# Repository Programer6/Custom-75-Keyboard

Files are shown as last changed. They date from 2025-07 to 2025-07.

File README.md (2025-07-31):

# Wireless 75% Keyboard

This is the documentation for  designed completely from scratch.

For the firmware, I chose ZMK. Since this is a wireless build using the `nice!nano`, ZMK's powerful features and Bluetooth support were a perfect fit, even if it meant a steeper learning curve than like KMK which I have used before.

# Hardware Features
- 74-key, 70% layout with a function row.
- Wireless Bluetooth connectivity via a `nice!nano` microcontroller.
- `MCP23017` I/O expander to simplify wiring and save controller pins.
- 1x Rotary Encoder for volume or scrolling.
- Onboard potentiometer for screen brightness adjustment.
- Powered by a LiPo battery.

## Images

| Schematic  |
| :---: |
| Screenshot 2025-07-31 at 1 52 47 PM|
| Screenshot 2025-07-31 at 1 53 02 PM |

| PCB Layout |
| :---: |
| Screenshot 2025-07-31 at 1 53 25 PM |

| 3D Case Design |
| :---: |
| Screenshot 2025-07-31 at 1 54 39 PM |

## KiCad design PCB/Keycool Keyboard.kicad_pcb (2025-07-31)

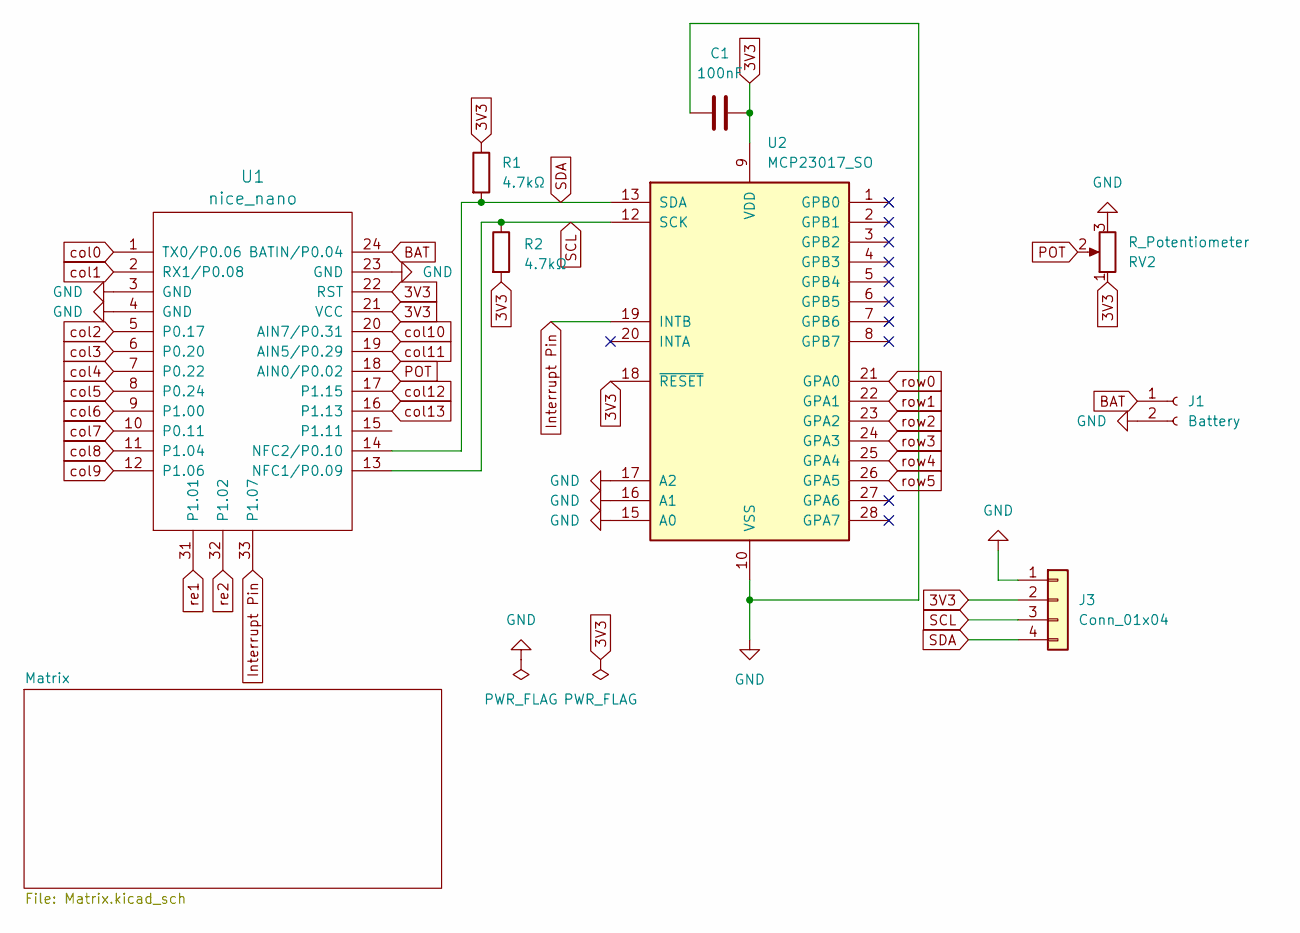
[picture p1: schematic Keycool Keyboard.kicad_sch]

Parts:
C1: 100nF; C_0805_2012Metric_Pad1.18x1.45mm_HandSolder
J1: Battery; JST_XH_B2B-XH-AM_1x02_P2.50mm_Vertical
J3: Conn_01x04; SSD1306-0.91-OLED-4pin-128x32
R1, R2: 4.7kΩ; R_0805_2012Metric_Pad1.20x1.40mm_HandSolder
RV2: R_Potentiometer; Sliding_Pot
U1: nice_nano
U2: MCP23017_SO; SOIC-28W_7.5x17.9mm_P1.27mm

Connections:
3V3: C1.2, J3.2, R1.1, R2.2, RV2.1, U1.21 (VCC), U1.22 (RST), U2.9 (VDD), U2.18 (~RESET)
BAT: J1.1, U1.24 (BATIN/P0.04)
GND: C1.1, J1.2, J3.1, RV2.3, U1.3 (GND), U1.4 (GND), U1.23 (GND), U2.10 (VSS), U2.15 (A0), U2.16 (A1), U2.17 (A2); also elsewhere on the board
Interrupt Pin: U1.33 (P1.07), U2.19 (INTB)
POT: RV2.2, U1.18 (AIN0/P0.02)
SCL: J3.3, R2.1, U1.13 (NFC1/P0.09), U2.12 (SCK)
SDA: J3.4, R1.2, U1.14 (NFC2/P0.10), U2.13 (SDA)
col0: U1.1 (TX0/P0.06); also elsewhere on the board
col1: U1.2 (RX1/P0.08); also elsewhere on the board
col2: U1.5 (P0.17); also elsewhere on the board
col3: U1.6 (P0.20); also elsewhere on the board
col4: U1.7 (P0.22); also elsewhere on the board
col5: U1.8 (P0.24); also elsewhere on the board
col6: U1.9 (P1.00); also elsewhere on the board
col7: U1.10 (P0.11); also elsewhere on the board
col8: U1.11 (P1.04); also elsewhere on the board
col9: U1.12 (P1.06); also elsewhere on the board
col10: U1.20 (AIN7/P0.31); also elsewhere on the board
col11: U1.19 (AIN5/P0.29); also elsewhere on the board
col12: U1.17 (P1.15); also elsewhere on the board
col13: U1.16 (P1.13); also elsewhere on the board
re1: U1.31 (P1.01); also elsewhere on the board
re2: U1.32 (P1.02); also elsewhere on the board
row0: U2.21 (GPA0); also elsewhere on the board
row1: U2.22 (GPA1); also elsewhere on the board
row2: U2.23 (GPA2); also elsewhere on the board
row3: U2.24 (GPA3); also elsewhere on the board
row4: U2.25 (GPA4); also elsewhere on the board
row5: U2.26 (GPA5); also elsewhere on the board

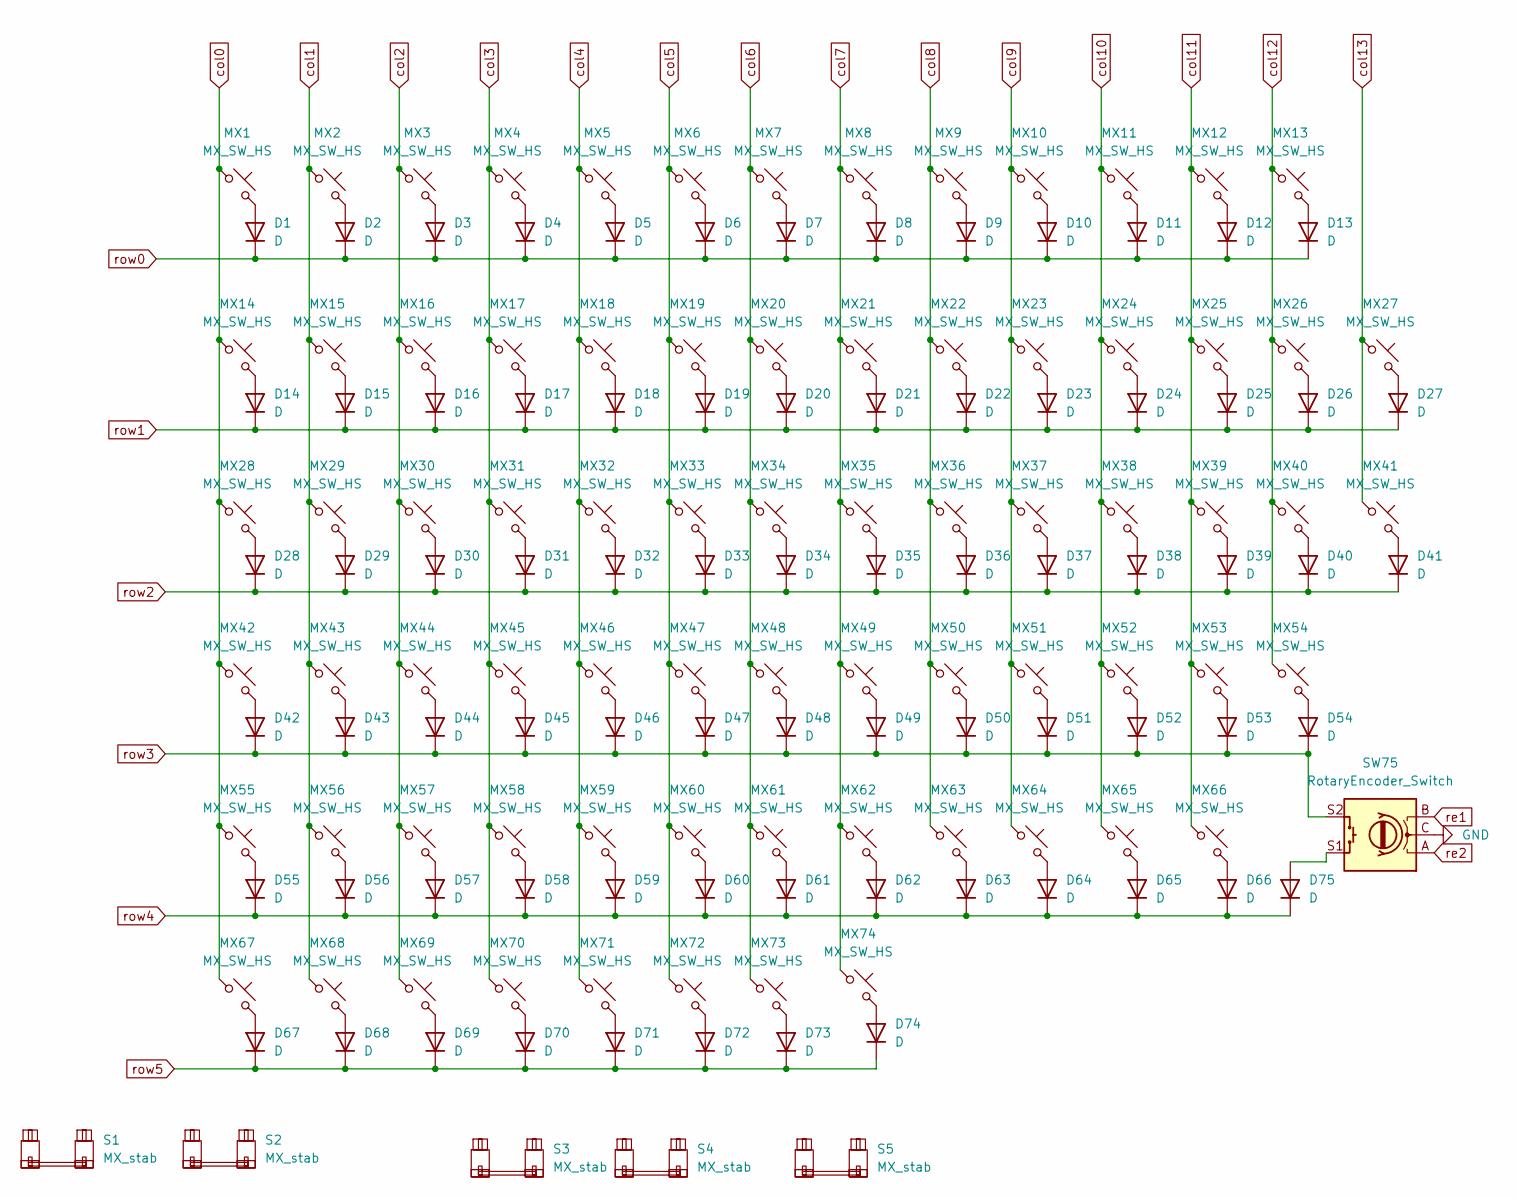
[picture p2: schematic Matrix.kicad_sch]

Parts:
D1, D2, D3, D4, D5, D6, D7, D8, D9, D10, D11, D12, D13, D14, D15, D16, D17, D18, D19, D20, D21, D22, D23, D24, D25, D26, D27, D28, D29, D30, D31, D32, D33, D34, D35, D36, D37, D38, D39, D40, D41, D42, D43, D44, D45, D46, D47, D48, D49, D50, D51, D52, D53, D54, D55, D56, D57, D58, D59, D60, D61, D62, D63, D64, D65, D66, D67, D68, D69, D70, D71, D72, D73, D74, D75: D; D_SOD-123
MX1, MX2, MX3, MX4, MX5, MX6, MX7, MX8, MX9, MX10, MX11, MX12, MX13, MX14, MX15, MX16, MX17, MX18, MX19, MX20, MX21, MX22, MX23, MX24, MX25, MX26, MX27, MX29, MX30, MX31, MX32, MX33, MX34, MX35, MX36, MX37, MX38, MX39, MX40, MX43, MX44, MX45, MX46, MX47, MX48, MX49, MX50, MX51, MX52, MX53, MX54, MX55, MX56, MX57, MX58, MX59, MX60, MX61, MX62, MX63, MX64, MX65, MX66, MX70: MX_SW_HS; SW_MX_HS_CPG151101S11_1u
MX28, MX41: MX_SW_HS; SW_MX_HS_CPG151101S11_1.5u
MX42: MX_SW_HS; SW_MX_HS_CPG151101S11_1.75u
MX67, MX68, MX69, MX71, MX72, MX73, MX74: MX_SW_HS; SW_MX_HS_CPG151101S11_1.25u
S1: MX_stab; STAB_MX_P_6.25u
S2: MX_stab; STAB_MX_P_2u
S3, S4: MX_stab; STAB_MX_P_2.25u
S5: MX_stab; STAB_MX_P_2.75u
SW75: RotaryEncoder_Switch; RotaryEncoder_Alps_EC11E-Switch_Vertical_H20mm_CircularMoun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

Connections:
GND: SW75.C; also elsewhere on the board
unnamed: D1.2 (A), MX1.2
unnamed: D2.2 (A), MX2.2
unnamed: D3.2 (A), MX3.2
unnamed: D4.2 (A), MX4.2
unnamed: D5.2 (A), MX5.2
unnamed: D6.2 (A), MX6.2
unnamed: D7.2 (A), MX7.2
unnamed: D8.2 (A), MX8.2
unnamed: D9.2 (A), MX9.2
unnamed: D10.2 (A), MX10.2
unnamed: D11.2 (A), MX11.2
unnamed: D12.2 (A), MX12.2
unnamed: D13.2 (A), MX13.2
unnamed: D14.2 (A), MX14.2
unnamed: D15.2 (A), MX15.2
unnamed: D16.2 (A), MX16.2
unnamed: D17.2 (A), MX17.2
unnamed: D18.2 (A), MX18.2
unnamed: D19.2 (A), MX19.2
unnamed: D20.2 (A), MX20.2
unnamed: D21.2 (A), MX21.2
unnamed: D22.2 (A), MX22.2
unnamed: D23.2 (A), MX23.2
unnamed: D24.2 (A), MX24.2
unnamed: D25.2 (A), MX25.2
unnamed: D26.2 (A), MX26.2
unnamed: D27.2 (A), MX27.2
unnamed: D28.2 (A), MX28.2
unnamed: D29.2 (A), MX29.2
unnamed: D30.2 (A), MX30.2
unnamed: D31.2 (A), MX31.2
unnamed: D32.2 (A), MX32.2
unnamed: D33.2 (A), MX33.2
unnamed: D34.2 (A), MX34.2
unnamed: D35.2 (A), MX35.2
unnamed: D36.2 (A), MX36.2
unnamed: D37.2 (A), MX37.2
unnamed: D38.2 (A), MX38.2
unnamed: D39.2 (A), MX39.2
unnamed: D40.2 (A), MX40.2
unnamed: D41.2 (A), MX41.2
unnamed: D42.2 (A), MX42.2
unnamed: D43.2 (A), MX43.2
unnamed: D44.2 (A), MX44.2
unnamed: D45.2 (A), MX45.2
unnamed: D46.2 (A), MX46.2
unnamed: D47.2 (A), MX47.2
unnamed: D48.2 (A), MX48.2
unnamed: D49.2 (A), MX49.2
unnamed: D50.2 (A), MX50.2
unnamed: D51.2 (A), MX51.2
unnamed: D52.2 (A), MX52.2
unnamed: D53.2 (A), MX53.2
unnamed: D54.2 (A), MX54.2
unnamed: D55.2 (A), MX55.2
unnamed: D56.2 (A), MX56.2
unnamed: D57.2 (A), MX57.2
unnamed: D58.2 (A), MX58.2
unnamed: D59.2 (A), MX59.2
unnamed: D60.2 (A), MX60.2
unnamed: D61.2 (A), MX61.2
unnamed: D62.2 (A), MX62.2
unnamed: D63.2 (A), MX63.2
unnamed: D64.2 (A), MX64.2
unnamed: D65.2 (A), MX65.2
unnamed: D66.2 (A), MX66.2
unnamed: D67.2 (A), MX67.2
unnamed: D68.2 (A), MX68.2
unnamed: D69.2 (A), MX69.2
unnamed: D70.2 (A), MX70.2
unnamed: D71.2 (A), MX71.2
unnamed: D72.2 (A), MX72.2
unnamed: D73.2 (A), MX73.2
unnamed: D74.2 (A), MX74.2
unnamed: D75.2 (A), SW75.S1
col0: MX1.1, MX14.1, MX28.1, MX42.1, MX55.1, MX67.1; also elsewhere on the board
col1: MX2.1, MX15.1, MX29.1, MX43.1, MX56.1, MX68.1; also elsewhere on the board
col2: MX3.1, MX16.1, MX30.1, MX44.1, MX57.1, MX69.1; also elsewhere on the board
col3: MX4.1, MX17.1, MX31.1, MX45.1, MX58.1, MX70.1; also elsewhere on the board
col4: MX5.1, MX18.1, MX32.1, MX46.1, MX59.1, MX71.1; also elsewhere on the board
col5: MX6.1, MX19.1, MX33.1, MX47.1, MX60.1, MX72.1; also elsewhere on the board
col6: MX7.1, MX20.1, MX34.1, MX48.1, MX61.1, MX73.1; also elsewhere on the board
col7: MX8.1, MX21.1, MX35.1, MX49.1, MX62.1, MX74.1; also elsewhere on the board
col8: MX9.1, MX22.1, MX36.1, MX50.1, MX63.1; also elsewhere on the board
col9: MX10.1, MX23.1, MX37.1, MX51.1, MX64.1; also elsewhere on the board
col10: MX11.1, MX24.1, MX38.1, MX52.1, MX65.1; also elsewhere on the board
col11: MX12.1, MX25.1, MX39.1, MX53.1, MX66.1; also elsewhere on the board
col12: MX13.1, MX26.1, MX40.1, MX54.1; also elsewhere on the board
col13: MX27.1, MX41.1; also elsewhere on the board
re1: SW75.B; also elsewhere on the board
re2: SW75.A; also elsewhere on the board
row0: D1.1 (K), D2.1 (K), D3.1 (K), D4.1 (K), D5.1 (K), D6.1 (K), D7.1 (K), D8.1 (K), D9.1 (K), D10.1 (K), D11.1 (K), D12.1 (K), D13.1 (K); also elsewhere on the board
row1: D14.1 (K), D15.1 (K), D16.1 (K), D17.1 (K), D18.1 (K), D19.1 (K), D20.1 (K), D21.1 (K), D22.1 (K), D23.1 (K), D24.1 (K), D25.1 (K), D26.1 (K), D27.1 (K); also elsewhere on the board
row2: D28.1 (K), D29.1 (K), D30.1 (K), D31.1 (K), D32.1 (K), D33.1 (K), D34.1 (K), D35.1 (K), D36.1 (K), D37.1 (K), D38.1 (K), D39.1 (K), D40.1 (K), D41.1 (K); also elsewhere on the board
row3: D42.1 (K), D43.1 (K), D44.1 (K), D45.1 (K), D46.1 (K), D47.1 (K), D48.1 (K), D49.1 (K), D50.1 (K), D51.1 (K), D52.1 (K), D53.1 (K), D54.1 (K), SW75.S2; also elsewhere on the board
row4: D55.1 (K), D56.1 (K), D57.1 (K), D58.1 (K), D59.1 (K), D60.1 (K), D61.1 (K), D62.1 (K), D63.1 (K), D64.1 (K), D65.1 (K), D66.1 (K), D75.1 (K); also elsewhere on the board
row5: D67.1 (K), D68.1 (K), D69.1 (K), D70.1 (K), D71.1 (K), D72.1 (K), D73.1 (K), D74.1 (K); also elsewhere on the board

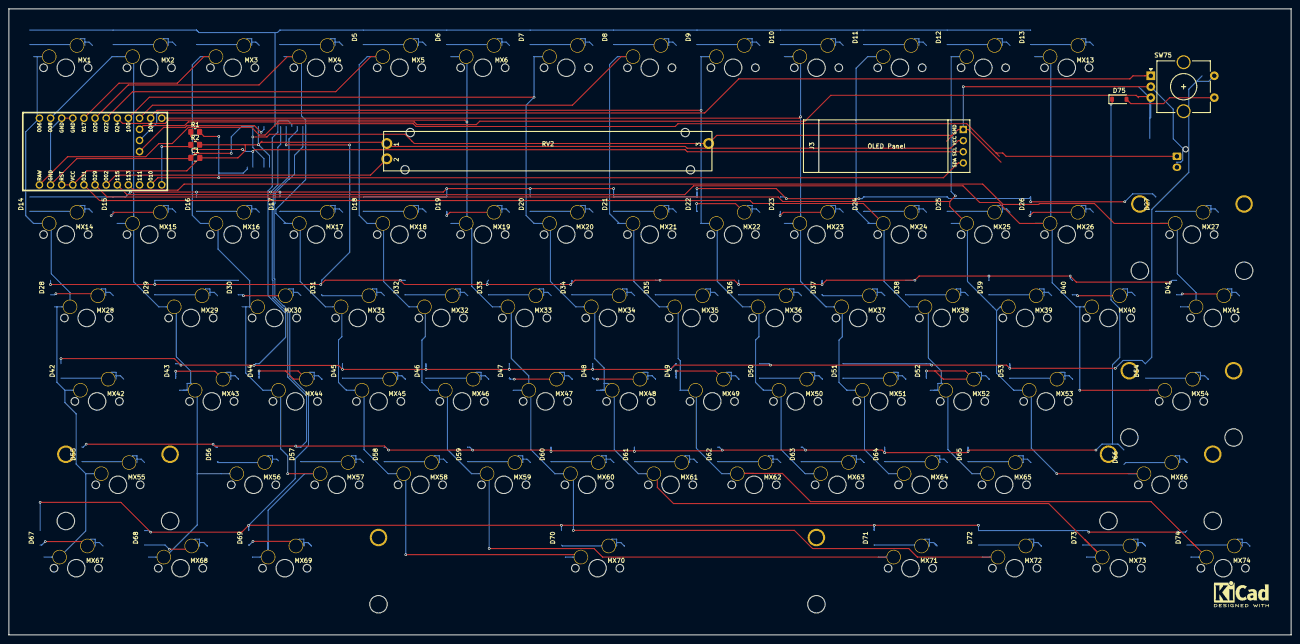
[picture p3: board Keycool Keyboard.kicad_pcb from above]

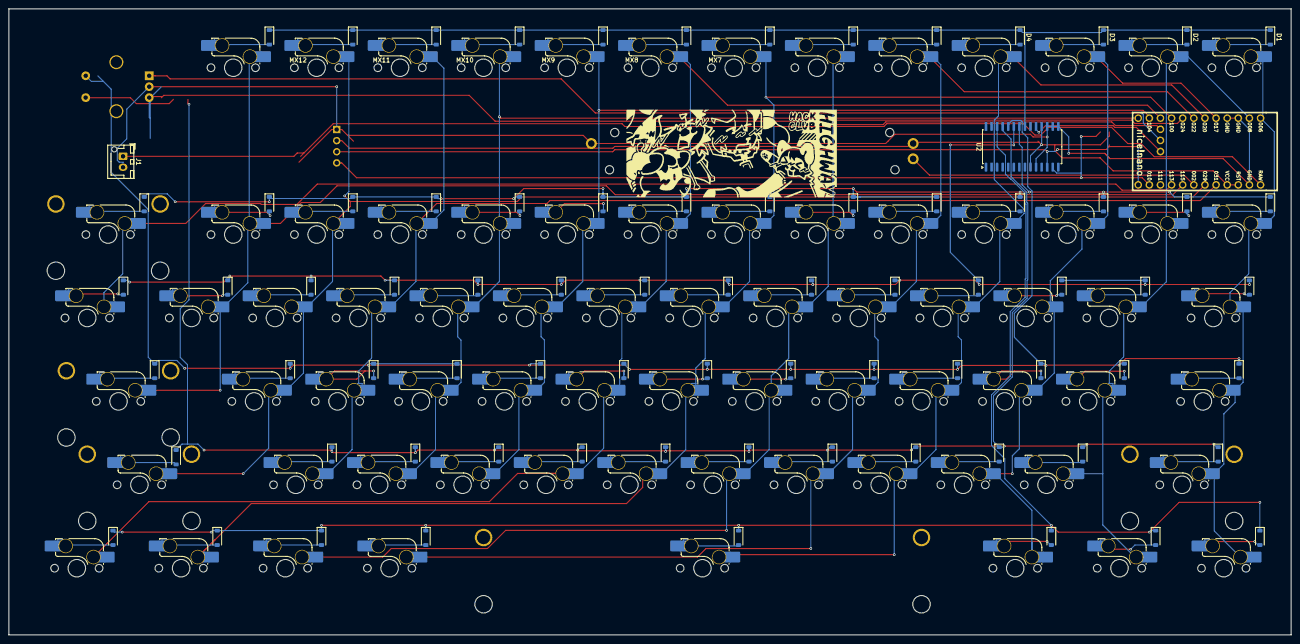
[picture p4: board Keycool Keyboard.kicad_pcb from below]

Board: 2 copper layers, 292.9 x 143.0 mm, 163 parts (151 on the bottom side), 104 nets.

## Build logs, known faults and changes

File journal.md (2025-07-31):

# Wireless 70% Keyboard: PCB & Firmware Documentation
_Made by: @Programer6 

| | |
|---|---|
| **Project Status** | In Development |
| **Total Time** | 25 Hours |
| **CAD Link** |  |
| **Repository** |https://github.com/Programer6/Custom-75-Keyboard|

---

## July 10, 2024 - Initial Schematic & Matrix Layout (4 hours)
Kicked off the project today by designing the core schematic in KiCad. The main focus was creating the key matrix for a custom 70% layout. I settled on a 6-row by 14-column matrix, which accommodates a function row, number row, three alpha rows, and a bottom modifier row.

Ensured, each switch (`MX1` through `MX74`) is paired with a diode (e.g., `D1`, `D2`). 
Screenshot 2025-07-31 at 1 38 59 PM

---

## July 11, 2024 - Microcontroller Selection & I/O Expansion (3 hours)
Today was all about selecting the core components and figuring out the GPIO strategy. For a wireless build, the **`nice!nano`** was the obvious choice due to its built-in wireless capabilities and excellent ZMK firmware support.

However, the 20 pins required for the 6x14 matrix would stretch the `nice!nano`'s available GPIOs to the limit, making PCB routing a nightmare. To solve this, I added an **`MCP23017` I/O expander**. 
Screenshot 2025-07-31 at 1 39 13 PM

---

## July 12, 2024 - cad (5 hours)
After finalizing the PCB, I exported the 3D model from KiCad and imported it into Fusion 360. I designed a simple and functional two-part case: a main body that holds the PCB and a top frame that acts as a switch plate and bezel.
Screenshot 2025-07-31 at 1 39 34 PM

---

## July 29, 2024 - ZMK Repository Setup (2.5 hours)

I followed the ZMK documentation to create a new `zmk-config` repository. This process involved running a setup script that creates the basic folder structure and configuration files. I named the new board `70keyboard` and set up the initial `build.yaml` file to target the `nice!nano_v2` board.
Screenshot 2025-07-31 at 1 41 33 PM

---

## July 30, 2024 - Writing the Device Tree Overlay (5.5 hours)

I mapped the 14 matrix columns directly to the nice!nano's pins and assigned the 6 rows to the MCP23017 I/O expander, configuring the I2C bus to let them communicate. And of course, I defined the two pins for the rotary encoder to complete the hardware setup.
Screenshot 2025-07-31 at 1 42 10 PM

---

## July 31, 2024 - Creating the Keymap (4 hours)
I built the keymap by laying out all the standard keys, creating an Fn layer for Bluetooth and bootloader shortcuts, and configuring the encoder to control volume with a push-to-mute function.

Screenshot 2025-07-31 at 1 42 01 PM
